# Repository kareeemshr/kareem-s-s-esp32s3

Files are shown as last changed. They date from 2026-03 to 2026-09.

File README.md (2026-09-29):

**quick warning, the traces for the 5volt regulator are too small for what it's max output is. I also apologize for it having too many layers since I'm not exactly the best at routing(I suck at it alot) I used more layers than necessary :(**

this is supposed to be a personal devboard using the esp32s,it has LED's in the shape of a heart,two cap touch plates and a buzzer.

**the led's are connected to io 48**

**the buzzer is connected to io 16**

**the cap touch plates are connected to io 4 and 8**

this doesnt have to be built with pcba but i **STRONGLY** recommend it cus i didint design it with hand soldering in mind because i personally cant get sorurce all the parts on the board on my own without paying outrageous prices for shipping so pcba is cheaper for me
heres the schem:

heres the pcb:

heres a 3d model:

heres my zineeee page:

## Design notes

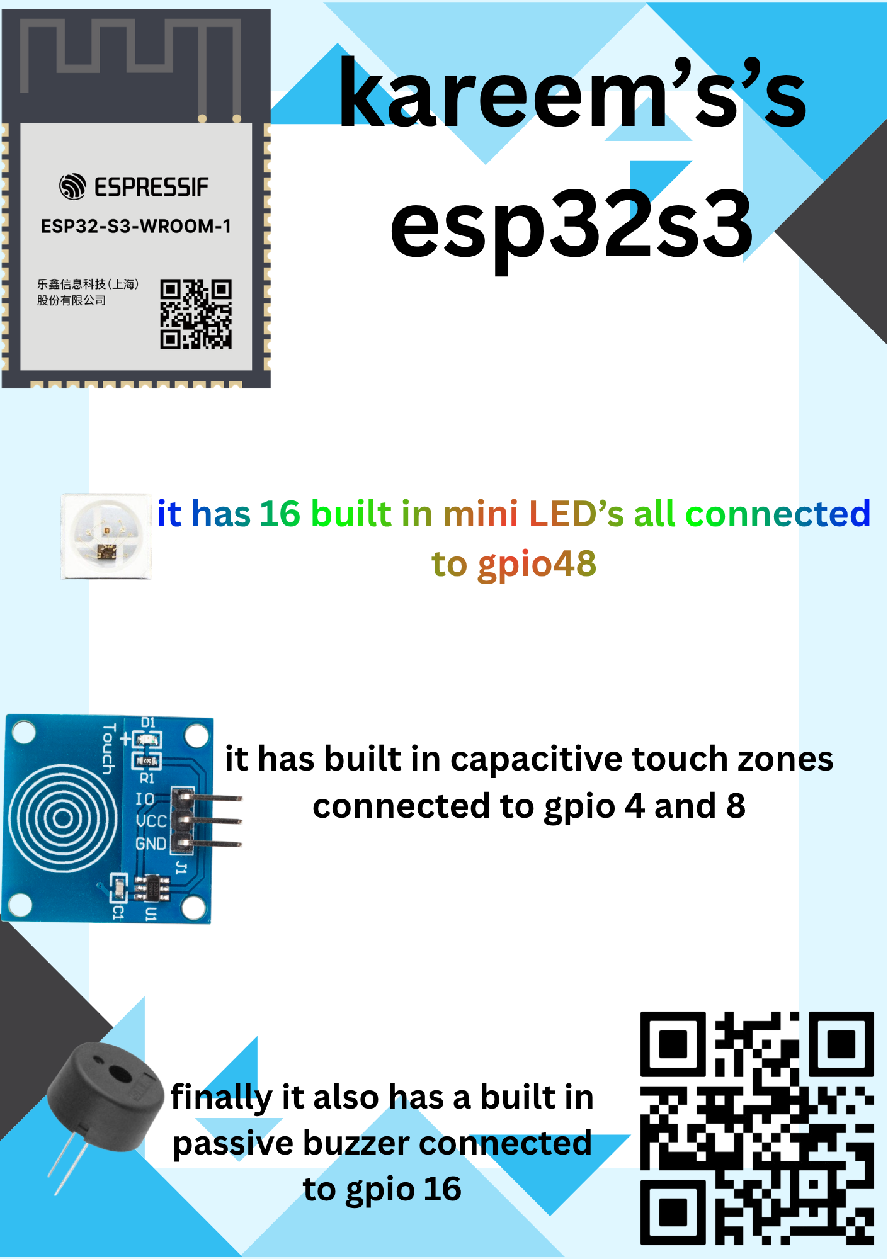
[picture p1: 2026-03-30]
kareem’s’s esp32s3.png

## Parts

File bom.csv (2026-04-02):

Designator | Footprint | Quantity | Value | link
5V1, 5V2 | PinHeader_1x01_P2.54mm_Vertical | 2 | Conn_01x01 | https://www.lcsc.com/product-detail/C492400.html
BOOT, RESET | SW_Push_SPST_NO_Alps_SKRK | 2 | SW_Push | https://www.lcsc.com/product-detail/C720477.html?s_z=s_Switches%257CTactile%2520Switches
BZ1 | Buzzer_12x9.5RM7.6 | 1 | Buzzer | https://www.lcsc.com/product-detail/C96256.html?s_z=n_12x9%2520buzzer
C1, C11, C14, C15, C2, C3, C5, C8 | 0402 | 8 | 10uF | https://www.lcsc.com/product-detail/C315248.html
C10, C12, C13, C16, C4, C6, C7, C9 | 0402 | 8 | 0.1uF | https://www.lcsc.com/product-detail/C60474.html
D1 | 0402 | 1 | LED | https://www.lcsc.com/product-detail/C30584803.html?s_z=n_smd%2520led%25200402
D10, D11, D12, D13, D14, D15, D16, D17, D2, D3, D4, D5, D6, D7, D8, D9 | LED_SK6812MINI_PLCC4_3.5x3.5mm_P1.75mm | 16 | SK6812MINI | https://www.lcsc.com/product-detail/C5149201.html?s_z=n_SK6812MINI
F1 | 0603 | 1 | 1A | https://www.lcsc.com/product-detail/C18203128.html?s_z=n_smd%2520fuse%25200603%252C1%252C1A%252C
FB1 | 0805 | 1 | 600Ω @ 100MHz, 500mA | https://www.lcsc.com/product-detail/C97120.html
J1 | USB_C_Receptacle_HRO_TYPE-C-31-M-12 | 1 | USB_C_Receptacle_USB2.0_14P | https://www.lcsc.com/product-detail/C2760486.html?s_z=n_usbc%2520receptical
J2, J3, J4, J5 | PinHeader_1x13_P2.54mm_Vertical | 4 | Conn_01x13 | https://www.lcsc.com/product-detail/C22465873.html?s_z=n_1-13P
J6 | PinHeader_1x03_P2.54mm_Vertical | 1 | Conn_01x03 | https://www.lcsc.com/product-detail/C2937625.html?s_z=n_1-03P
R1, R2 | 0402 | 2 | 5.1k | https://www.lcsc.com/product-detail/C105872.html
R10 | 0402 | 1 | 470 | https://www.lcsc.com/product-detail/C114877.html?s_z=n_%2520470ohm%25200402
R11, R13 | 0402 | 2 | 100 | https://www.lcsc.com/product-detail/C106232.html?s_z=n_100ohm%25200402
R12 | 0402 | 1 | 165 | https://www.lcsc.com/product-detail/C2076669.html?s_z=n_165ohm%25200402
R3, R4 | 0402 | 2 | 27 | https://www.lcsc.com/product-detail/C138021.html?s_z=n_27ohm%25200402
R5, R8 | 0402 | 2 | 10K | https://www.lcsc.com/product-detail/C60490.html?s_z=n_10kohm%25200402
R6, R7 | 0402 | 2 | 4.7K | https://www.lcsc.com/product-detail/C105871.html?s_z=n_4.7kohm%25200402
R9 | 0402 | 1 | 330 | https://www.lcsc.com/product-detail/C105875.html?s_z=n_330ohm%25200402
U1 | ESP32-S3-WROOM-1 | 1 | ESP32-S3-WROOM-1 | https://www.lcsc.com/product-detail/C2913202.html?s_z=n_esp32
U3 | SOT-23-5 | 1 | AP2112K-1.2 | https://www.lcsc.com/product-detail/C460310.html?s_z=n_AP2112K-1.2
U4 | SOT-23-6 | 1 | USBLC6-2SC6 | https://www.lcsc.com/product-detail/C7519.html?s_z=n_USBLC6-2SC6
U5 | TO-263-5_TabPin3 | 1 | MIC29302WU | https://www.lcsc.com/product-detail/C2995533.html?s_z=n_MIC29302WU

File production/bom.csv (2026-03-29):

Designator | Footprint | Quantity | Value | LCSC Part #
5V1, 5V2 | PinHeader_1x01_P2.54mm_Vertical | 2 | Conn_01x01
BOOT, RESET | SW_Push_SPST_NO_Alps_SKRK | 2 | SW_Push
BUZZER | Buzzer_12x9.5RM7.6 | 1 | Buzzer
C1, C11, C14, C15, C2, C3, C5, C8 | 0402 | 8 | 10uF
C10, C12, C13, C16, C4, C6, C7, C9 | 0402 | 8 | 0.1uF
D1 | 0402 | 1 | LED
D10, D11, D12, D13, D14, D15, D16, D17, D2, D3, D4, D5, D6, D7, D8, D9 | LED_SK6812MINI_PLCC4_3.5x3.5mm_P1.75mm | 16 | SK6812MINI
F1 | 0603 | 1 | 1A
FB1 | 0805 | 1 | 600Ω @ 100MHz, 500mA
J1 | USB_C_Receptacle_HRO_TYPE-C-31-M-12 | 1 | USB_C_Receptacle_USB2.0_14P
J2, J3 | PinHeader_2x13_P2.54mm_Vertical | 2 | Conn_02x13_Odd_Even
R1, R2 | 0402 | 2 | 5.1k
R10 | 0402 | 1 | 470
R11, R13 | 0402 | 2 | 100
R12 | 0402 | 1 | 165
R3, R4 | 0402 | 2 | 27
R5, R8 | 0402 | 2 | 10K
R6, R7 | 0402 | 2 | 4.7K
R9 | 0402 | 1 | 330
U1 | ESP32-S3-WROOM-1 | 1 | ESP32-S3-WROOM-1
U3 | SOT-23-5 | 1 | AP2112K-1.2
U4 | SOT-23-6 | 1 | USBLC6-2SC6
U5 | TO-263-5_TabPin3 | 1 | MIC29302WU

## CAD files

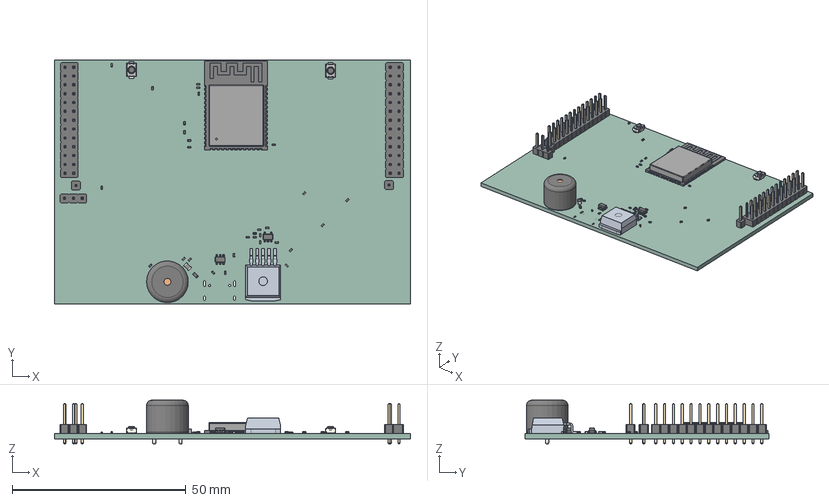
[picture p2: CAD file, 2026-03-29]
source.step
102.3 x 70.0 x 12.5 mm
C_0402_1005Metric x 16
PinHeader_2x13_P2.54mm_Vertical x 2
R_0402_1005Metric x 13
PinHeader_1x03_P2.54mm_Vertical
SOT-23-5
Fuse_0603_1608Metric
ESP32-S3-WROOM-1
PinHeader_1x01_P2.54mm_Vertical x 2
L_0805_2012Metric
SW_Push_SPST_NO_Alps_SKRK x 2
source 1.29.1
Buzzer_12x9.5RM7.6
LED_0402_1005Metric
SOT-23-6
source_PCB

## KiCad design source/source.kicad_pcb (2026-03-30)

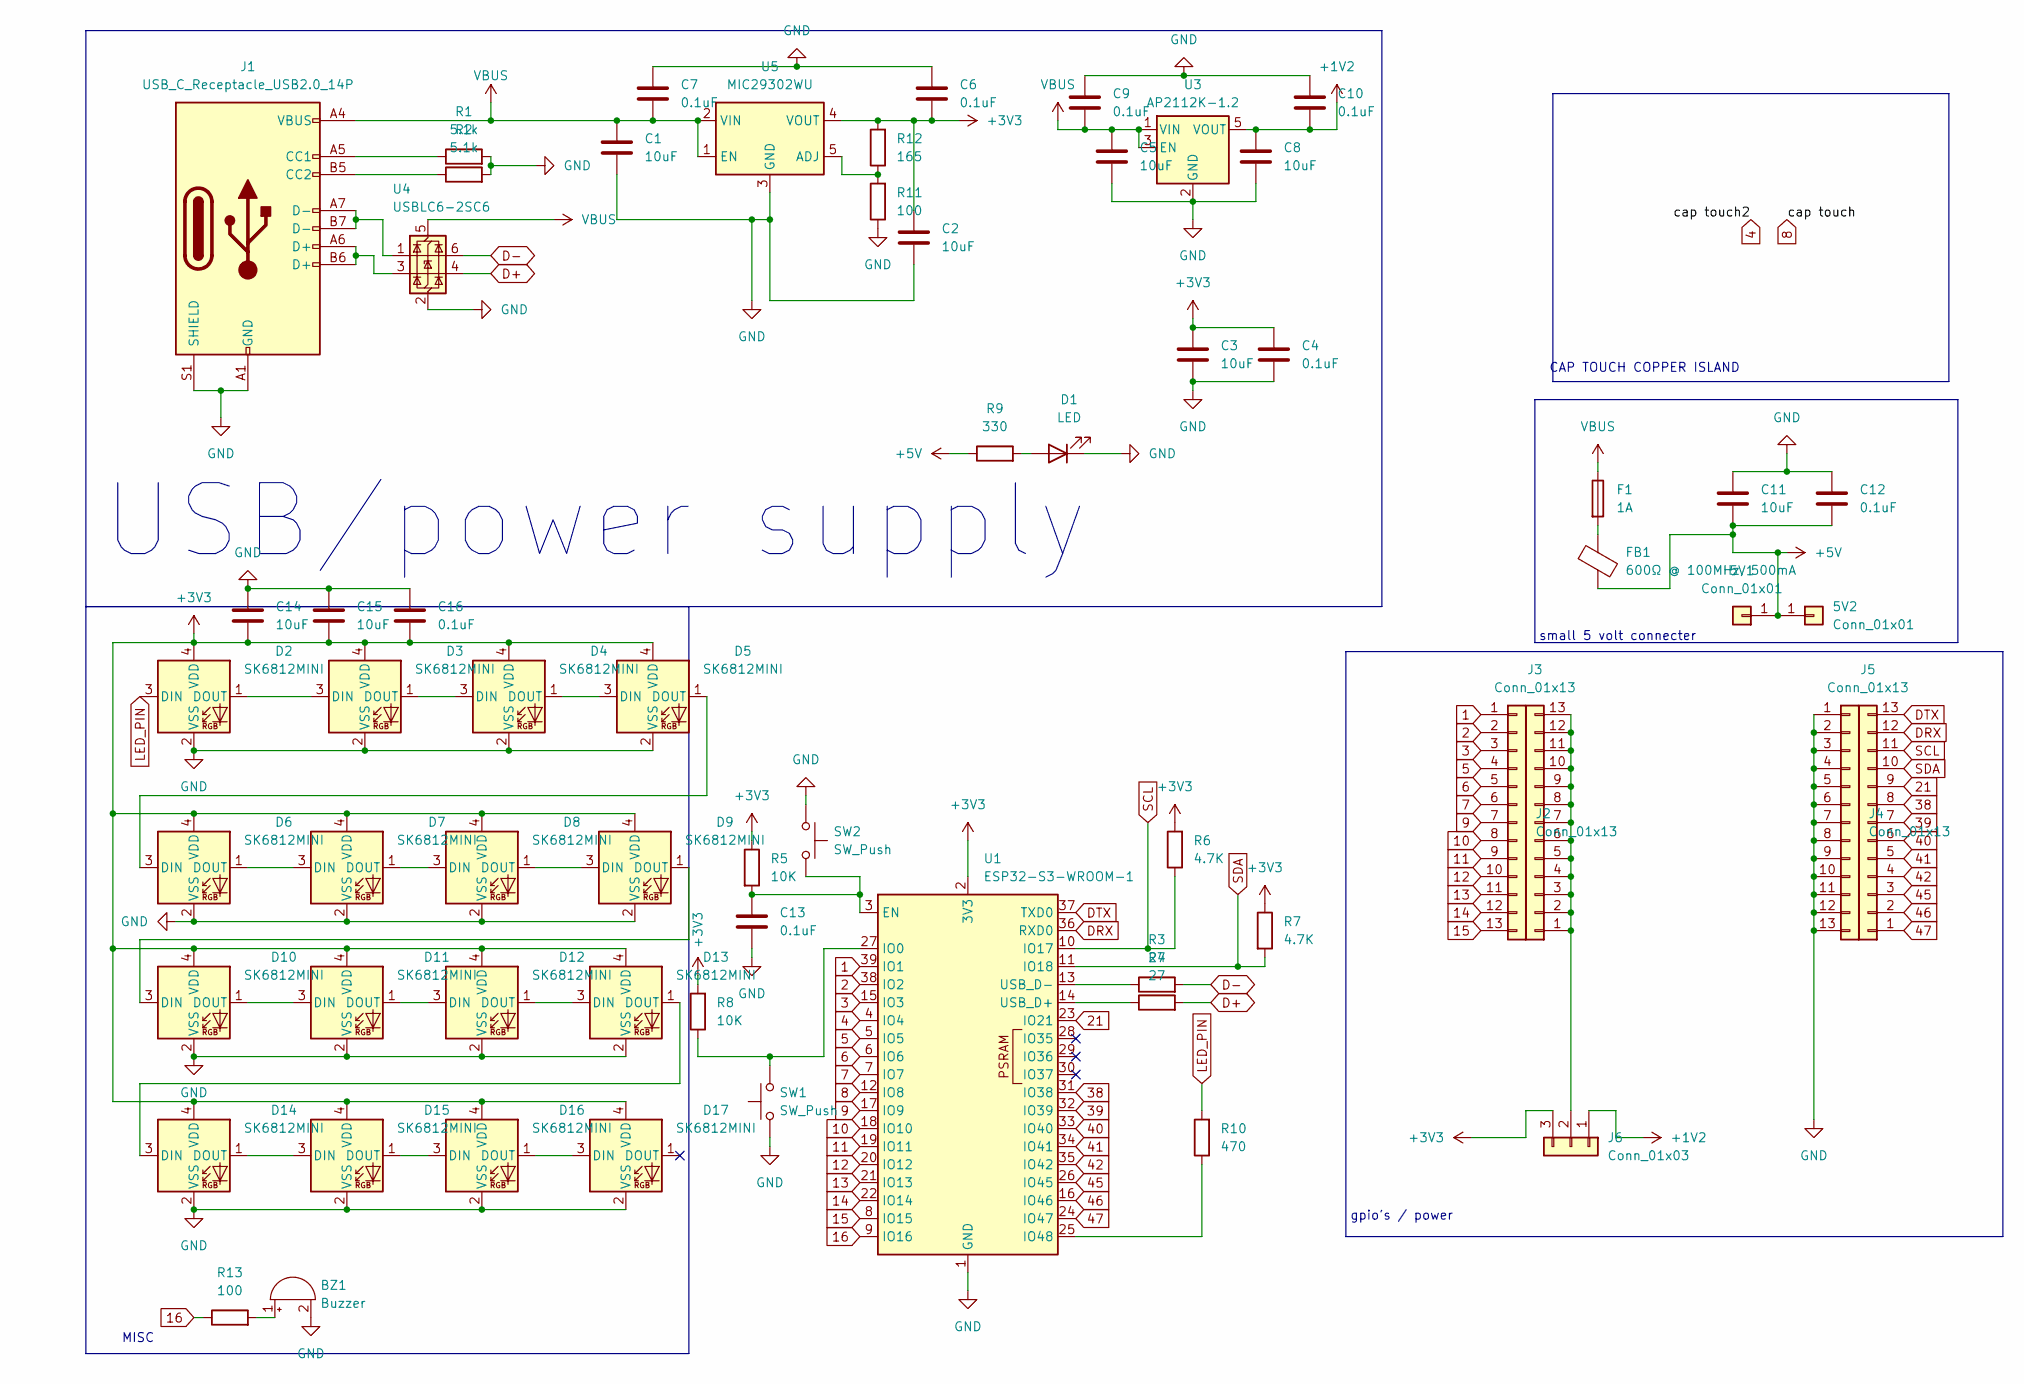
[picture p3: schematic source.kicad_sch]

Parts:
5V1, 5V2: Conn_01x01; PinHeader_1x01_P2.54mm_Vertical
BZ1: Buzzer; Buzzer_12x9.5RM7.6
C1, C2, C3, C5, C8, C11, C14, C15: 10uF; C_0402_1005Metric
C4, C6, C7, C9, C10, C12, C13, C16: 0.1uF; C_0402_1005Metric
D1: LED; LED_0402_1005Metric
D2, D3, D4, D5, D6, D7, D8, D9, D10, D11, D12, D13, D14, D15, D16, D17: SK6812MINI; LED_SK6812MINI_PLCC4_3.5x3.5mm_P1.75mm
F1: 1A; Fuse_0603_1608Metric
FB1: 600Ω @ 100MHz, 500mA; L_0805_2012Metric
J1: USB_C_Receptacle_USB2.0_14P; USB_C_Receptacle_HRO_TYPE-C-31-M-12
J2, J3, J4, J5: Conn_01x13; PinHeader_1x13_P2.54mm_Vertical
J6: Conn_01x03; PinHeader_1x03_P2.54mm_Vertical
R1, R2: 5.1k; R_0402_1005Metric
R3, R4: 27; R_0402_1005Metric
R5, R8: 10K; R_0402_1005Metric
R6, R7: 4.7K; R_0402_1005Metric
R9: 330; R_0402_1005Metric
R10: 470; R_0402_1005Metric
R11, R13: 100; R_0402_1005Metric
R12: 165; R_0402_1005Metric
SW1, SW2: SW_Push; SW_Push_SPST_NO_Alps_SKRK
U1: ESP32-S3-WROOM-1
U3: AP2112K-1.2; SOT-23-5
U4: USBLC6-2SC6; SOT-23-6
U5: MIC29302WU; TO-263-5_TabPin3

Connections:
1: J2.1, U1.39 (IO1)
2: J2.2, U1.38 (IO2)
3: J2.3, U1.15 (IO3)
4: U1.4 (IO4)
5: J2.4, U1.5 (IO5)
6: J2.5, U1.6 (IO6)
7: J2.6, U1.7 (IO7)
8: U1.12 (IO8)
9: J2.7, U1.17 (IO9)
10: J2.8, U1.18 (IO10)
11: J2.9, U1.19 (IO11)
12: J2.10, U1.20 (IO12)
13: J2.11, U1.21 (IO13)
14: J2.12, U1.22 (IO14)
15: J2.13, U1.8 (IO15)
16: R13.1, U1.9 (IO16)
21: J5.9, U1.23 (IO21)
38: J5.8, U1.31 (IO38)
39: J5.7, U1.32 (IO39)
40: J5.6, U1.33 (IO40)
41: J5.5, U1.34 (IO41)
42: J5.4, U1.35 (IO42)
45: J5.3, U1.26 (IO45)
46: J5.2, U1.16 (IO46)
47: J5.1, U1.24 (IO47)
+1V2: C8.1, C10.2, J6.1, U3.5 (VOUT)
+3V3: C2.1, C3.1, C4.1, C6.2, C14.1, C15.1, C16.1, D2.4 (VDD), D3.4 (VDD), D4.4 (VDD), D5.4 (VDD), D6.4 (VDD), D7.4 (VDD), D8.4 (VDD), D9.4 (VDD), D10.4 (VDD), D11.4 (VDD), D12.4 (VDD), D13.4 (VDD), D14.4 (VDD), D15.4 (VDD), D16.4 (VDD), D17.4 (VDD), J6.3, R5.1, R6.2, R7.1, R8.2, R12.2, U1.2 (3V3), U5.4 (VOUT)
+5V: 5V1.1, 5V2.1, C11.2, C12.2, FB1.2, R9.1
D+: R4.2, U4.4 (I/O2)
D-: R3.2, U4.6 (I/O1)
DRX: J5.12, U1.36 (RXD0)
DTX: J5.13, U1.37 (TXD0)
GND: BZ1.2 (-), C1.2, C2.2, C3.2, C4.2, C5.2, C6.1, C7.1, C8.2, C9.1, C10.1, C11.1, C12.1, C13.2, C14.2, C15.2, C16.2, D1.1 (K), D2.2 (VSS), D3.2 (VSS), D4.2 (VSS), D5.2 (VSS), D6.2 (VSS), D7.2 (VSS), D8.2 (VSS), D9.2 (VSS), D10.2 (VSS), D11.2 (VSS), D12.2 (VSS), D13.2 (VSS), D14.2 (VSS), D15.2 (VSS), D16.2 (VSS), D17.2 (VSS), J1.A1 (GND), J1.A12 (GND), J1.B1 (GND), J1.B12 (GND), J1.S1 (SHIELD), J4.1, J4.2, J4.3, J4.4, J4.5, J4.6, J4.7, J4.8, J4.9, J4.10, J4.11, J4.12, J4.13, R1.2, R2.2, R11.1, SW1.1, SW2.1, U1.1 (GND), U1.40 (GND), U1.41 (GND), U3.2 (GND), U4.2 (GND), U5.3 (GND); also elsewhere on the board
LED_PIN: D2.3 (DIN), R10.2
unnamed: BZ1.1 (+), R13.2
unnamed: D1.2 (A), R9.2
unnamed: D2.1 (DOUT), D3.3 (DIN)
unnamed: D3.1 (DOUT), D4.3 (DIN)
unnamed: D4.1 (DOUT), D5.3 (DIN)
unnamed: D5.1 (DOUT), D6.3 (DIN)
unnamed: D6.1 (DOUT), D7.3 (DIN)
unnamed: D7.1 (DOUT), D8.3 (DIN)
unnamed: D8.1 (DOUT), D9.3 (DIN)
unnamed: D9.1 (DOUT), D10.3 (DIN)
unnamed: D10.1 (DOUT), D11.3 (DIN)
unnamed: D11.1 (DOUT), D12.3 (DIN)
unnamed: D12.1 (DOUT), D13.3 (DIN)
unnamed: D13.1 (DOUT), D14.3 (DIN)
unnamed: D14.1 (DOUT), D15.3 (DIN)
unnamed: D15.1 (DOUT), D16.3 (DIN)
unnamed: D16.1 (DOUT), D17.3 (DIN)
unnamed: F1.2, FB1.1
unnamed: J1.A5 (CC1), R1.1
unnamed: J1.B5 (CC2), R2.1
unnamed: J1.A6 (D+), J1.B6 (D+), U4.3 (I/O2)
unnamed: J1.A7 (D-), J1.B7 (D-), U4.1 (I/O1)
unnamed: J3.1, J3.2, J3.3, J3.4, J3.5, J3.6, J3.7, J3.8, J3.9, J3.10, J3.11, J3.12, J3.13, J6.2
unnamed 57: C13.1, R5.2, SW2.2, U1.3 (EN); also elsewhere on the board
unnamed 58: R8.1, SW1.2, U1.27 (IO0); also elsewhere on the board
unnamed: R10.1, U1.25 (IO48)
unnamed: R4.1, U1.14 (USB_D+)
unnamed: R3.1, U1.13 (USB_D-)
unnamed: R11.2, R12.1, U5.5 (ADJ)
SCL: J5.11, R6.1, U1.10 (IO17)
SDA: J5.10, R7.2, U1.11 (IO18)
VBUS: C1.1, C5.1, C7.2, C9.2, F1.1, J1.A4 (VBUS), J1.A9 (VBUS), J1.B4 (VBUS), J1.B9 (VBUS), U3.1 (VIN), U3.3 (EN), U4.5 (VBUS), U5.1 (EN), U5.2 (VIN)

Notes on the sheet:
MISC
gpio's / power
CAP TOUCH COPPER ISLAND
small 5 volt connecter
USB/power supply

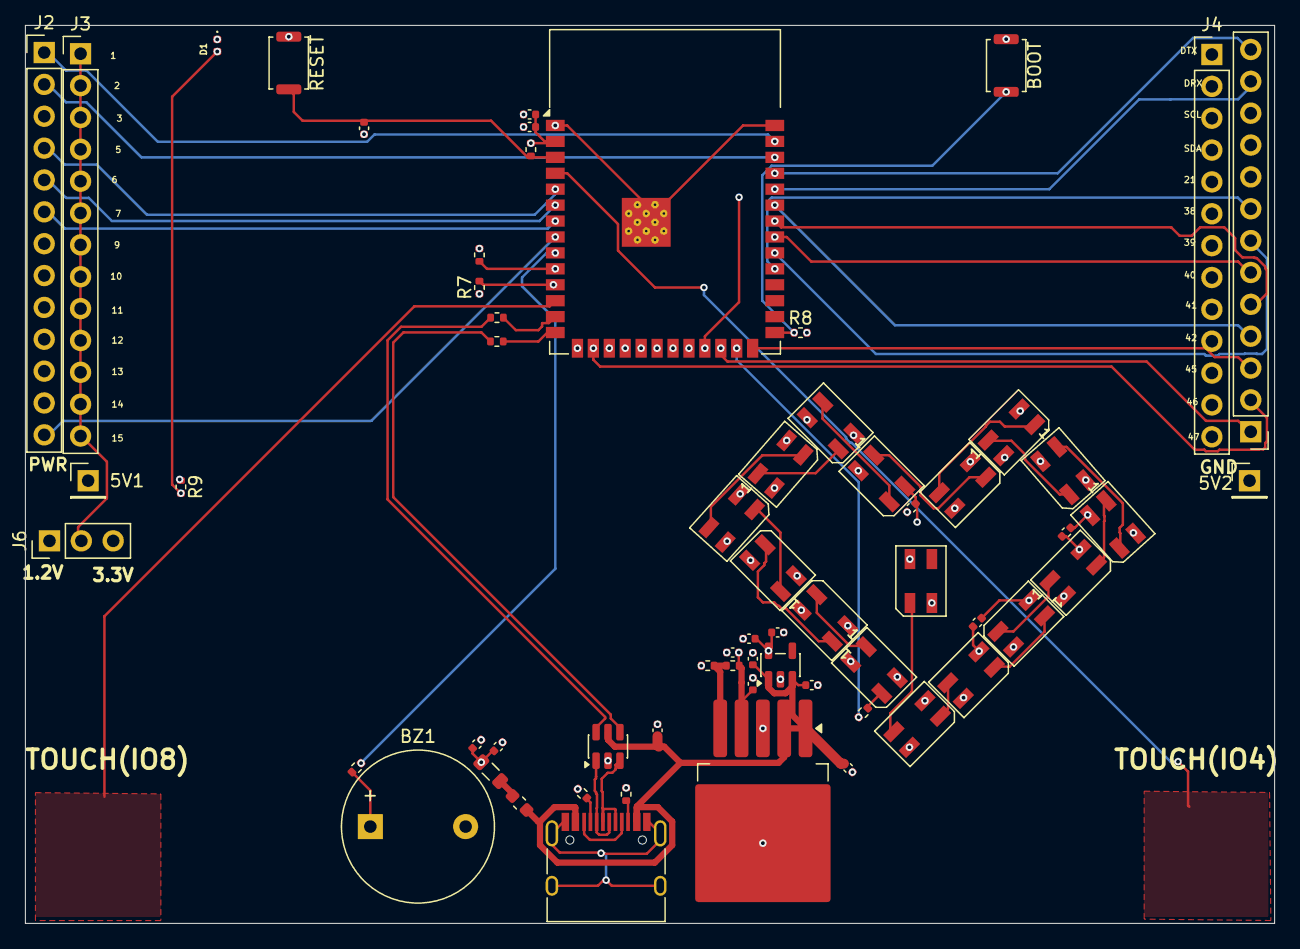
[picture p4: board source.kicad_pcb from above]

Board: 4 copper layers, 99.6 x 71.6 mm, 63 parts (0 on the bottom side), 64 nets.

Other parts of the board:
BOOT: SW_Push; SW_Push_SPST_NO_Alps_SKRK
RESET: SW_Push; SW_Push_SPST_NO_Alps_SKRK

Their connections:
GND: BOOT.1, RESET.1; also elsewhere on the board
unnamed 57: RESET.2; also elsewhere on the board
unnamed 58: BOOT.2; also elsewhere on the board

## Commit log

2026-03-29 Update README with PCB and 3D model images
    Added images of the PCB and 3D model to the README.
2026-03-30 Update BOM with new part numbers and descriptions
    [BOM_ESP32S3_Devboard.csv]
2026-04-02 Recommend PCBA for easier sourcing of components
    Added recommendation for PCBA due to sourcing issues.
2026-04-02 Add component links to bom.csv
    Added links to components in BOM for easy access.
    [bom.csv]
2026-04-02 Update BOM entries in bom.csv
    Replaced the existing BOM data with updated entries.
    [bom.csv]
2026-09-29 Add warning about regulator traces and routing issues
    Added a warning about the traces for the 5-volt regulator and acknowledged routing issues.
